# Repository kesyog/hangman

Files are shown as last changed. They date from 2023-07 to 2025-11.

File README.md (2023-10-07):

# hangman ⚖️

<p align="center">
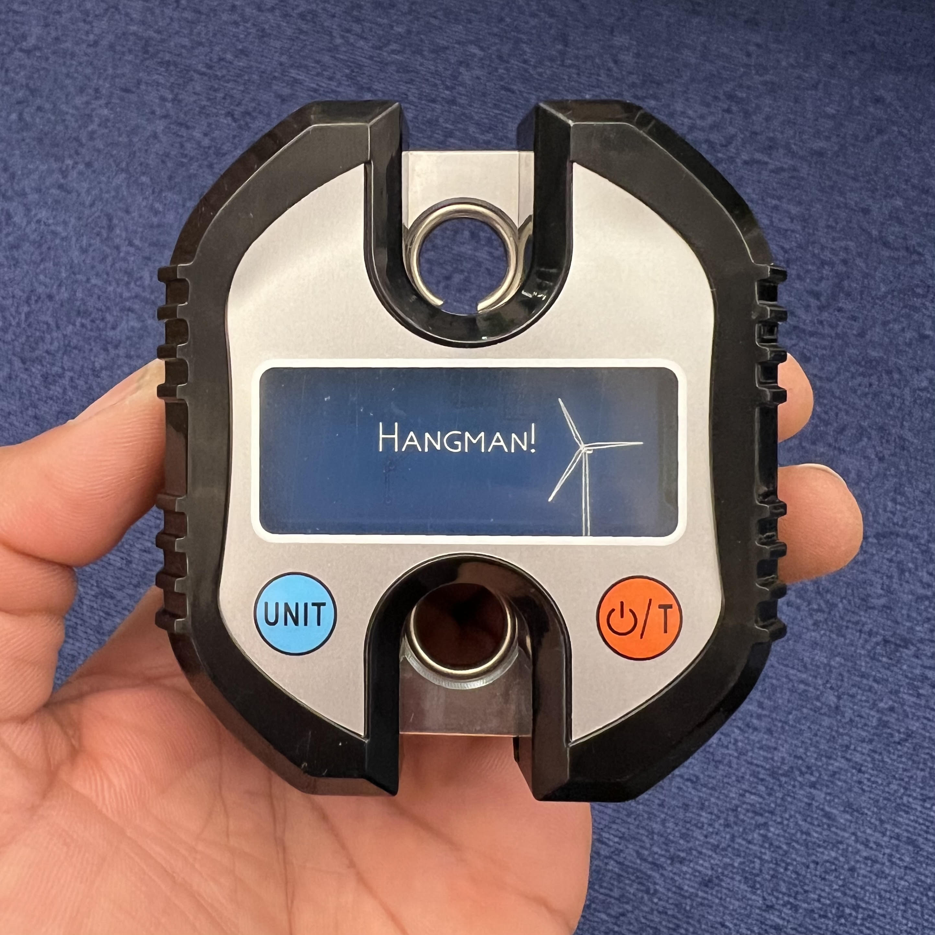
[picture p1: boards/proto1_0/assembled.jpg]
Assembled prototype P1.0 unit
  
</p>

Hangman is a Bluetooth-enabled crane scale. It's intended use is as a climbing training and rehab
tool, but it can be used anywhere that requires measuring force or weight.

The hardware retrofits a cheap (~$23) 150kg crane scale from Amazon with a custom PCB based around a
Nordic nRF52 microcontroller and a differential ADC. The firmware uses [Embassy][Embassy], an
embedded async framework written in Rust, as well as Nordic's SoftDevice Bluetooth stack.

## Why?

Crane scales have become popular in the climbing community as a means to train and rehab fingers.
This is a fun project to learn and practice various concepts I was unfamiliar or rusty with: BLE
101, async Rust on embedded, nRF52 development, SMT soldering and PCB design, etc. Maybe it'll even
help my fingers get stronger.

## Status

The scale is feature-complete. Weight measurement works great with the [Progressor API][API] and
compatible tools. Battery life is guesstimated to be in the range of several months to a couple of
years depending on usage.

There are still a few more software updates planned. See the Issues section for the major ones.

### Hardware revisions

#### P1.0

See title picture. A custom PCB based on a Fanstel BT832 nRF52832-based module and a Texas
Instruments ADS1230 ADC. Thanks to a better ADC and PCB layout, noise performance should be improved
over previous revisions and most importantly, it's much prettier.

#### P0.0

A custom PCB based on a nRF52840 USB dongle and an HX711 ADC, the same differential ADC used on the
Tindeq.

<p align="center">
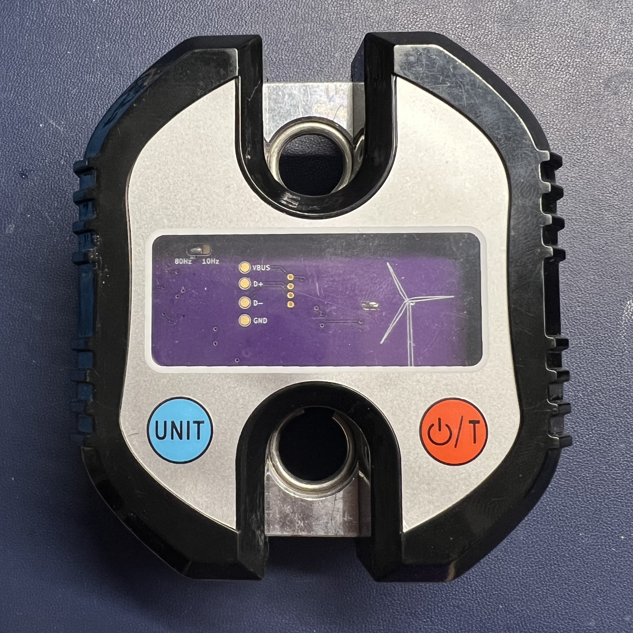
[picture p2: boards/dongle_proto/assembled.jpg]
Assembled prototype P0.0 unit
  
</p>

## Shoutouts

* The [Embassy](https://embassy.dev) project for bringing asynchronous Rust to the embedded world.
  and creating an easy to use wrapper around the Nordic SoftDevice Bluetooth stack.
* [Bumble](https://github.com/google/bumble) for BLE testing and prototyping.
* Texas Instruments for their excellent reference materials on load cell circuit design and PCB
  layout.
* [Tindeq](https://tindeq.com/product/progressor/) for making an amazing product and app and opening
  their BLE API to third-party developers. Go buy one!

## Disclaimer

This is not an officially supported Google product. Wouldn't that be funny though?

This has no affiliation with Tindeq.

[API]: https://tindeq.com/progressor_api/
[Embassy]: https://embassy.dev/

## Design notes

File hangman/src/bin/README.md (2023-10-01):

# Binaries

* `dongle`: prototype based on a nRF52840 USB dongle and an HX711 ADC.
* `calibration`: uses the button for a manual calibration flow. Obsolete now that calibration over
BLE is supported.
* `proto0_0`: custom PCB based on a nRF52840 USB dongle and an HX711 ADC. Fits <https://www.amazon.com/gp/product/B07D5RVW2L>.
* `proto1_0`: custom PCB based on a Fanstel nRF52832 module and a TI ADS1230 ADC. Fits <https://www.amazon.com/gp/product/B07D5RVW2L>.

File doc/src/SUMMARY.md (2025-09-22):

# Summary

[Hangman](./README.md)

- [Development]()
- [Hardware]()
- [Assembly](./assembly.md)
- [Bringup](./bringup.md)
- [Calibration](./calibration.md)

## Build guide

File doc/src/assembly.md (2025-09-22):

# Assembly

How to assemble the boards into the housings

## Instructions
- Test the scale to make sure that it generally works
- Disassemble fully, keep the screws
<p align="center">
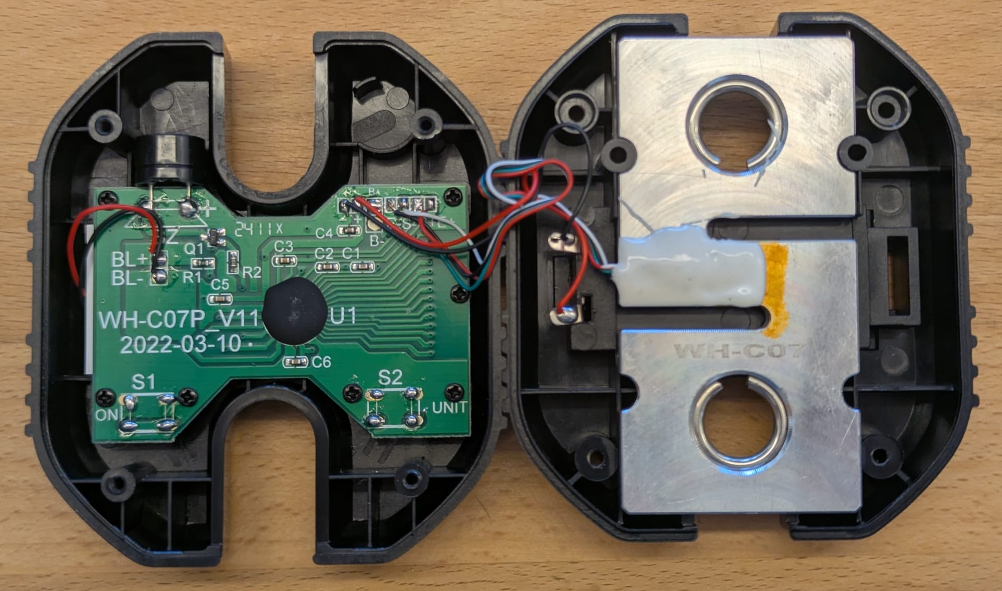
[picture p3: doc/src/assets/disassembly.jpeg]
Partially disassembled scale
  
</p>

- Swap over the wires to the new, already populated PCB
- Screw the new PCB back in 
<p align="center">
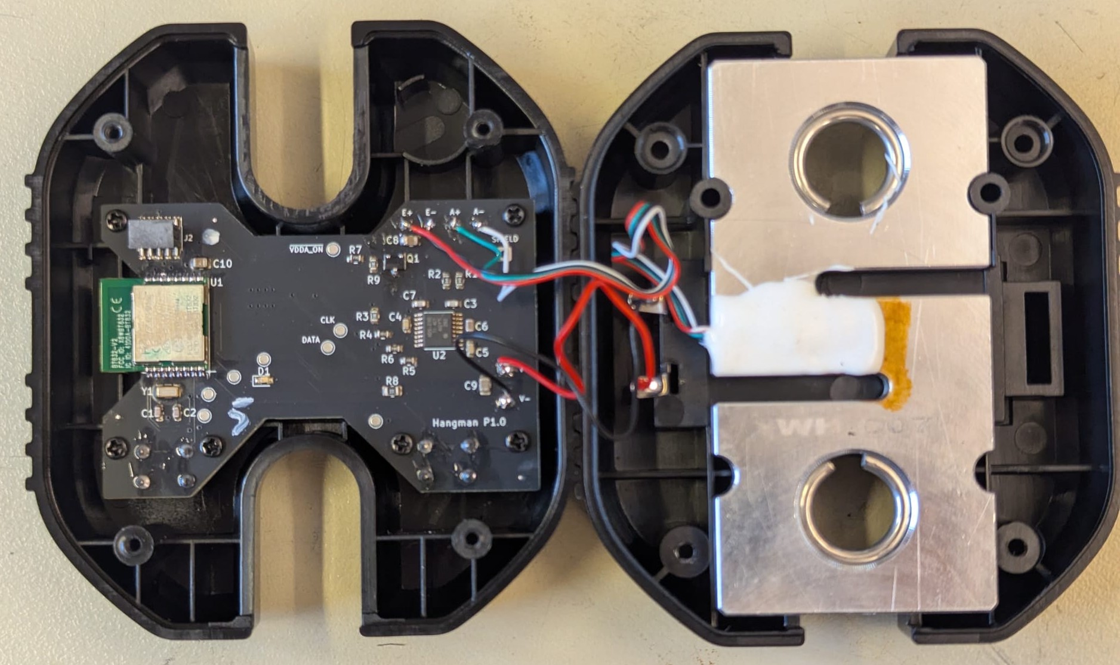
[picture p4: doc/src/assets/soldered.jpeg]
Soldered and semi-assembled scale
  
</p>

- Measure the voltage input pins for shorts (to prevent stupid errors)
- Power on the board with batteries or a lab bench power supply
- Do the [Bringup](./bringup.md)
- Close the housing and screw it shut, don't pinch any wires or strip any screws 
- Do the [Calibration](./calibration.md)
- Done!

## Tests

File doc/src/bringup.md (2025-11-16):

# Bringup

How to get the board from being assembled to being functional

## nRF Command Line Tools + Segger J-Link

Note that Nordic encourages the use of the nRF Util over nrfjprog. I've found nrfjprog to be more
reliable in the past and haven't migrated to nRF Util, but it's probably not too hard to figure out
the equivalent commands.

### Prereqs

* Obtain a Segger J-Link debugger
* Download the [nRF Command Line Tools](https://www.nordicsemi.com/Products/Development-tools/nRF-Command-Line-Tools)
* Download the SoftDevice s113 from <https://www.nordicsemi.com/Products/Development-software/S113>

### Instructions

1. Connect your debugger.
1. Flash the SoftDevice. This generally only needs to be done once.

   ```sh
   nrfjprog --family nrf52 --program s113_nrf52_7.2.0_softdevice.hex --chiperase --verify --reset
   ```

   Your .hex filename may differ.
1. Flash the hangman firmware:

   ```sh
   DEFMT_LOG=info cargo run --release --bin proto1_0 --features nrf52832
   ```

## Windows + ST-Link

Instructions using Windows, WSL and a ST-Link

### Requirements

- Working WSL2
- ST-Link, with installed drivers (I used a ST-Link V2-1, borrowed from a Nucleo Board)
- Install usbipd-win on windows: run `winget install --interactive --exact dorssel.usbipd-win` in a windows terminal
- Install required packages in wsl: `sudo apt install build-essential`
- Install rust: https://rustup.rs/
- Install probe-rs: https://probe.rs/
- Install OpenOCD in WSL: `sudo apt install openocd` in wsl
- Download the SoftDevice for the chip from NRF (I used s113_nrf52_7.3.0_softdevice.hex)

### Flashing

- Connect the ST-Link
- Follow these instructions to get the ST-Link connected to WSL: https://learn.microsoft.com/de-de/windows/wsl/connect-usb
 - `usbipd list`
 - `usbipd bind --busid <busid>`
 - `usbipd attach --wsl --busid <busid>`
- Connect the board to the ST-Link correctly
- Power the board
- Run `openocd -f /usr/share/openocd/scripts/interface/stlink.cfg -f /usr/share/openocd/scripts/target/nrf52.cfg`
- In a seperate terminal run `telnet localhost 4444`
- Use `targets` you can check that you can see the nrf52 target
- Run `init`, `halt`, `nrf5 mass_erase`, `program /full/path/.../s113_nrf52_7.3.0_softdevice.hex verify`
- Run `exit`in telnet shell
- Exit OpenOCD with CTRL+C
- Build and flash the code with `cargo run --bin proto1_0 --release`
- Done! Further flashing etc. should not require reflashing the SoftDevice

### Notes

- If you just want to flash the softdevice in one command you can do it like this: `openocd -f /usr/share/openocd/scripts/interface/stlink.cfg -f /usr/share/openocd/scripts/target/nrf52.cfg -c "init; halt; nrf5 mass_erase; program /full/path/.../s113_nrf52_7.3.0_softdevice.hex preverify verify; shutdown"`

### Sources

- https://www.jentsch.io/nrf51822-flashen-mit-st-link-v2-und-openocd/
- https://github.com/seemoo-lab/openhaystack/wiki/Flashing-nRF-with-OpenOCD---ST-Link
- https://github.com/lupyuen/stm32bluepill-mynewt-sensor/blob/nrf52/scripts/nrf52/flash-boot.sh
- https://www.youtube.com/watch?v=R5wub5ywzTU&t=197s
- https://www.reddit.com/r/embedded/comments/1k9v4vr/stm32_cmake_stlinkv3pwr_on_windows_in_2025/?show=original
- https://github.com/dorssel/usbipd-win/wiki/WSL-support
- https://discuss.ardupilot.org/t/help-setting-up-openocd-with-st-link-in-wsl2/112271
- https://hackmd.io/@aeefs2Y8TMms-cjTDX4cfw/r1fqAa_Da
- https://learn.microsoft.com/de-de/windows/wsl/connect-usb

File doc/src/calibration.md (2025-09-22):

# Calibration

Hangman uses a two-point calibration routine where one of the points is zero. Calibration needs to
be run once before use. The generated calibration constants are saved across power cycles so there
shouldn't be a need to be calibrate multiple times, but you can re-calibrate at any time if you feel
like the scale is inaccurate.

## Instructions

1. Install the nRF Connect app or any similar tool that can be used to connect to BLE devices and
write data to GATT characteristics.
1. Wake up Hangman by pressing the power button.
1. Connect to Hangman using nRF Connect. It'll be named something starting with `Progressor`.
1. Hang "zero" weight from the scale. It's okay if this isn't actually zero. What's important is
that you know the difference in weight between this stage and the second calibration point. Any
deviation from zero at this point will be tared out later.
1. Write the ByteArray `6900000000` to the `7e4e1703-1ea6-40c9-9dcc-13d34ffead57` GATT
characteristic. This should be the only writable characteristic. This sends the 0x69
(`AddCalibrationPoint`) opcode along with 0.0 as a 32-bit float.
1. Add a known reference weight to the scale, ideally something that's at or more than the expected
maximum weight but less than 150kg, the maximum capacity of the scale.
1. Convert the known weight, in kg, to a 32-bit floating point number in little-endian format. Write
`69 <your hex bytes here>` to the same characteristic as earlier. As an example, if your known
weight were 120.0 kg, you would send `690000f042`.
1. If you mess up entering in either meaurement, feel free to resend the corresponding command.
1. Once you're set, write `0x6A` to the same characteristic to save the calibration.
1. At this point, disconnect from Hangman and test it out using the Tindeq mobile app or something
compatible.

## Tips

* If the measurements are wildly off after calibration, try re-calibrating and using a big-endian
float. Different programs disagree on how these bytes should be entered 🤷
* The two calibration points can be written in any order. However, it's probably a little better to
write the zero point first, in case there is some hysteresis.
* 0x69 is the `AddCalibrationPoint` opcode.
* 0x6A is the `SaveCalibration` opcode.

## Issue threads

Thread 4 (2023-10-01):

Documentation tracking

kesyog, 2023-10-01:
* [ ] Calibration instructions
* [ ] Board errata
* [ ] Do a pass of rustdoc comments

cicatrix87, 2024-02-10:
Are you still working on a documentation? I would like to build some of those devices for a few friends, but how its now im a bit confused what and how to do it.

kesyog, 2024-02-11:
Hey, I wasn't planning on writing step-by-step detailed instructions for building these. The process is a bit involved, especially if you don't have soldering and embedded experience and equipment. Also, I'd rather steer people toward getting a [Tindeq](https://tindeq.com/product/progressor) to support their product.

I am planning on writing a high-level guide to document the project further and steer people around some of the obstacles I ran into. It'll live in the attached page, https://kesyog.github.io/hangman. Unfortunately, it's hard to find the time and energy to do this sort of thing so I probably won't get around to it for a while (likely on the order of months at least).

That said, if you do have the background, curiosity, and time to fill in the gaps, the quick summary:
1. Buy this crane scale: https://www.amazon.com/dp/B07MTFXSJW
1. Order the PCB's and electronic parts. I can dig up a parts list if you're interested.
1. Assemble the PCB, ideally with SMT soldering equipment.
1. Replace the existing PCB in the crane scale with your PCB and solder the load cell and battery wires to the PCB.
1. Flash the s113 NRF SoftDevice image using `nrfjprog --family nrf52 --program <path to hex file> --chiperase --verify`. I used a Segger J-Link for flashing.
1. [Install Rust](https://rustup.rs)
1. Build and flash the image. The repo is set up such that `cargo run` will build the image and use `probe-rs` to flash the image.
1. Perform two-point calibration over BLE: https://kesyog.github.io/hangman/calibration.html
1. Enjoy.

Hope that helps!

cicatrix87, 2024-02-12:
I already have a similiar crane scale that could work, in the end those load cells should work identical or? I will check if the originial PCB in this one has the same dimensions and screw points as yours. A Parts List would be highly recommended so a BOM&CPL that i could order everything together with the PCB. Sure i could buy a Tindeq but its more fun like this,

kesyog, 2024-02-12:
It'll almost certainly work with a different load cell as essentially all load cell circuitry works the same way. Most cheap ones have the same 4-wire connection. Some more expensive ones have an additional two sense wires and/or an extra shield line, especially if they have a long cable, but shield can be tied to ground and IIRC the sense lines can either be ignored or tied to the corresponding +/- output lines.

Some things to look out for if you're using a different load cell:
* I'm guessing the the board size and screw points will be different. If needed, you could re-design the boards using the same schematic files to fit the new part. The layout is pretty spacious so there's lots of leeway to move components around to fit a shape
* Make sure the crane scale housing is plastic, not metal, so that it doesn't block wireless transmission.
* Ideally, put the BLE antenna as far away as possible from the metal load cell. I'm not sure how much this matters for the purposes of the crane scale use case where we're probably only ever transmitting over a few meters, but the datasheets recommend keeping the antenna away from metal.
* Make sure the max battery voltage is okay for the nRF52832 microcontroller
* Don't worry about the load cell weight rating. The firmware doesn't care. Once you calibrate it, things should just work, whether you're using a 50kg load cell or a 1000kg load cell.

Also, you'll need a known weight to do calibration, so it's helpful to have an unmodified crane scale (or any kind of scale) to measure your calibration weight.

Here's the part list I used:

| Part              | Ref des     | Part number/Digikey part number   | Notes                                                                                     |
|-------------------|-------------|-----------------------------------|-------------------------------------------------------------------------------------------|
| SWD connector     |             | 1849-PM20B05VBDN-ND               |                                                                                           |
| Fanstel BT module |             | BT832                             | https://www.fanstel.com/bt832-1-1                                                         |
| Push-button       |             | 2223-TS02-66-70-BK-160-LCR-D-ND   |                                                                                           |
| TI ADC            |             | ADS1230                           | https://www.digikey.com/en/products/detail/texas-instruments/ADS1230IPWR/1689136          |
| PFET              | Q1          | SSM3J378RLFCT-ND                  |                                                                                           |
| 32.768kHz crystal |             | SC32S-7PF20PPM                    | https://www.digikey.com/en/products/detail/seiko-instruments/SC32S-7PF20PPM/4931504       |
| RLED              | R8          | RMCF0805JT100RCT-ND               | (for debugging)                                                                           |
| LED               |             | 3147-B1911USD-20D000114U1930CT-ND | (for debugging)                                                                           |
| 10pF              | C1 C2       | 1276-1069-1-ND                    |                                                                                           |
| 0.1uF filter caps | C6          | 490-GRMJN65C1H104JE01JCT-ND       | https://www.digikey.com/en/products/detail/murata-electronics/GRMJN65C1H104JE01J/19115572 |
| 10nF filter caps  | C3 C7       | 490-GRT1885C1E103JA02JCT-ND       |                                                                                           |
| 0.1uF             | C4 C5       | 1276-1935-1-ND                    |                                                                                           |
| 10uF              | C8 C9 C10   | 1276-2399-1-ND                    |                                                                                           |
|                47 | R4 R5 R6 R7 | RMCF0603FT47R5CT-ND               |                                                                                           |
|               100 | R1 R2       | RMCF0603FT100RCT-ND               |                                                                                           |
| 49.9k             | R3 R9       | RMCF0603FT49K9CT-ND               |                                                                                           |

Let me know if/when you get it working. I won't be able to give too much debugging help, but I might be able to point you to relevant docs I found helpful.

roviraleix, 2024-06-20:
Hello,

any updates on it? I've got an nRF52840 board and a HX711 and would like to try to make it work with the tindeq app.
I was wondering if it would be possible to flash the nRF with the tindeq firmware.

Regards and congrats for this nice project!

RaBoom, 2025-08-10:
Hi,

as I want to order a few boards, I have put together a (slightly updated) digikey BOM:
https://www.digikey.de/de/mylists/list/5ZJBLSF5TQ
I have selected a new LED (other one was not in Stock anymore) and put in a 330 Ohm resistor for the debug LED.

To save some money I have opted to buy the TI ADS1230IPWR and the headers (20021121-00010C4LF) at LCSC.

I will order the PCBs and stencils at JLC and assemble them at home and will try to document my process a bit.
If anyone in europe wants an assembled board shoot me a message, I will probably have some left over to offer for approx. 20€+ Shipping (I hope thats okay for you @kesyog)

Cicatr1x, 2025-08-11:
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

If you have some spares leftover, than i would probably take two units.

RaBoom, 2025-09-03:
> If you have some spares leftover, than i would probably take two units.

Sure! I've finished the first one and it works great!

Contact me at rboomgaarden at gmx dot de
I'll immediately delete this comment and will rely on your notifications so that you are able to see this :)

kesyog, 2025-09-03:
ah sorry about that. IIRC I ran into those issues during assembly and fixed the Kicad files but must have forgotten to re-generate the gerbers. Do you think it'd be better if I just removed the gerbers from git so that the Kicad files are the single source of truth?

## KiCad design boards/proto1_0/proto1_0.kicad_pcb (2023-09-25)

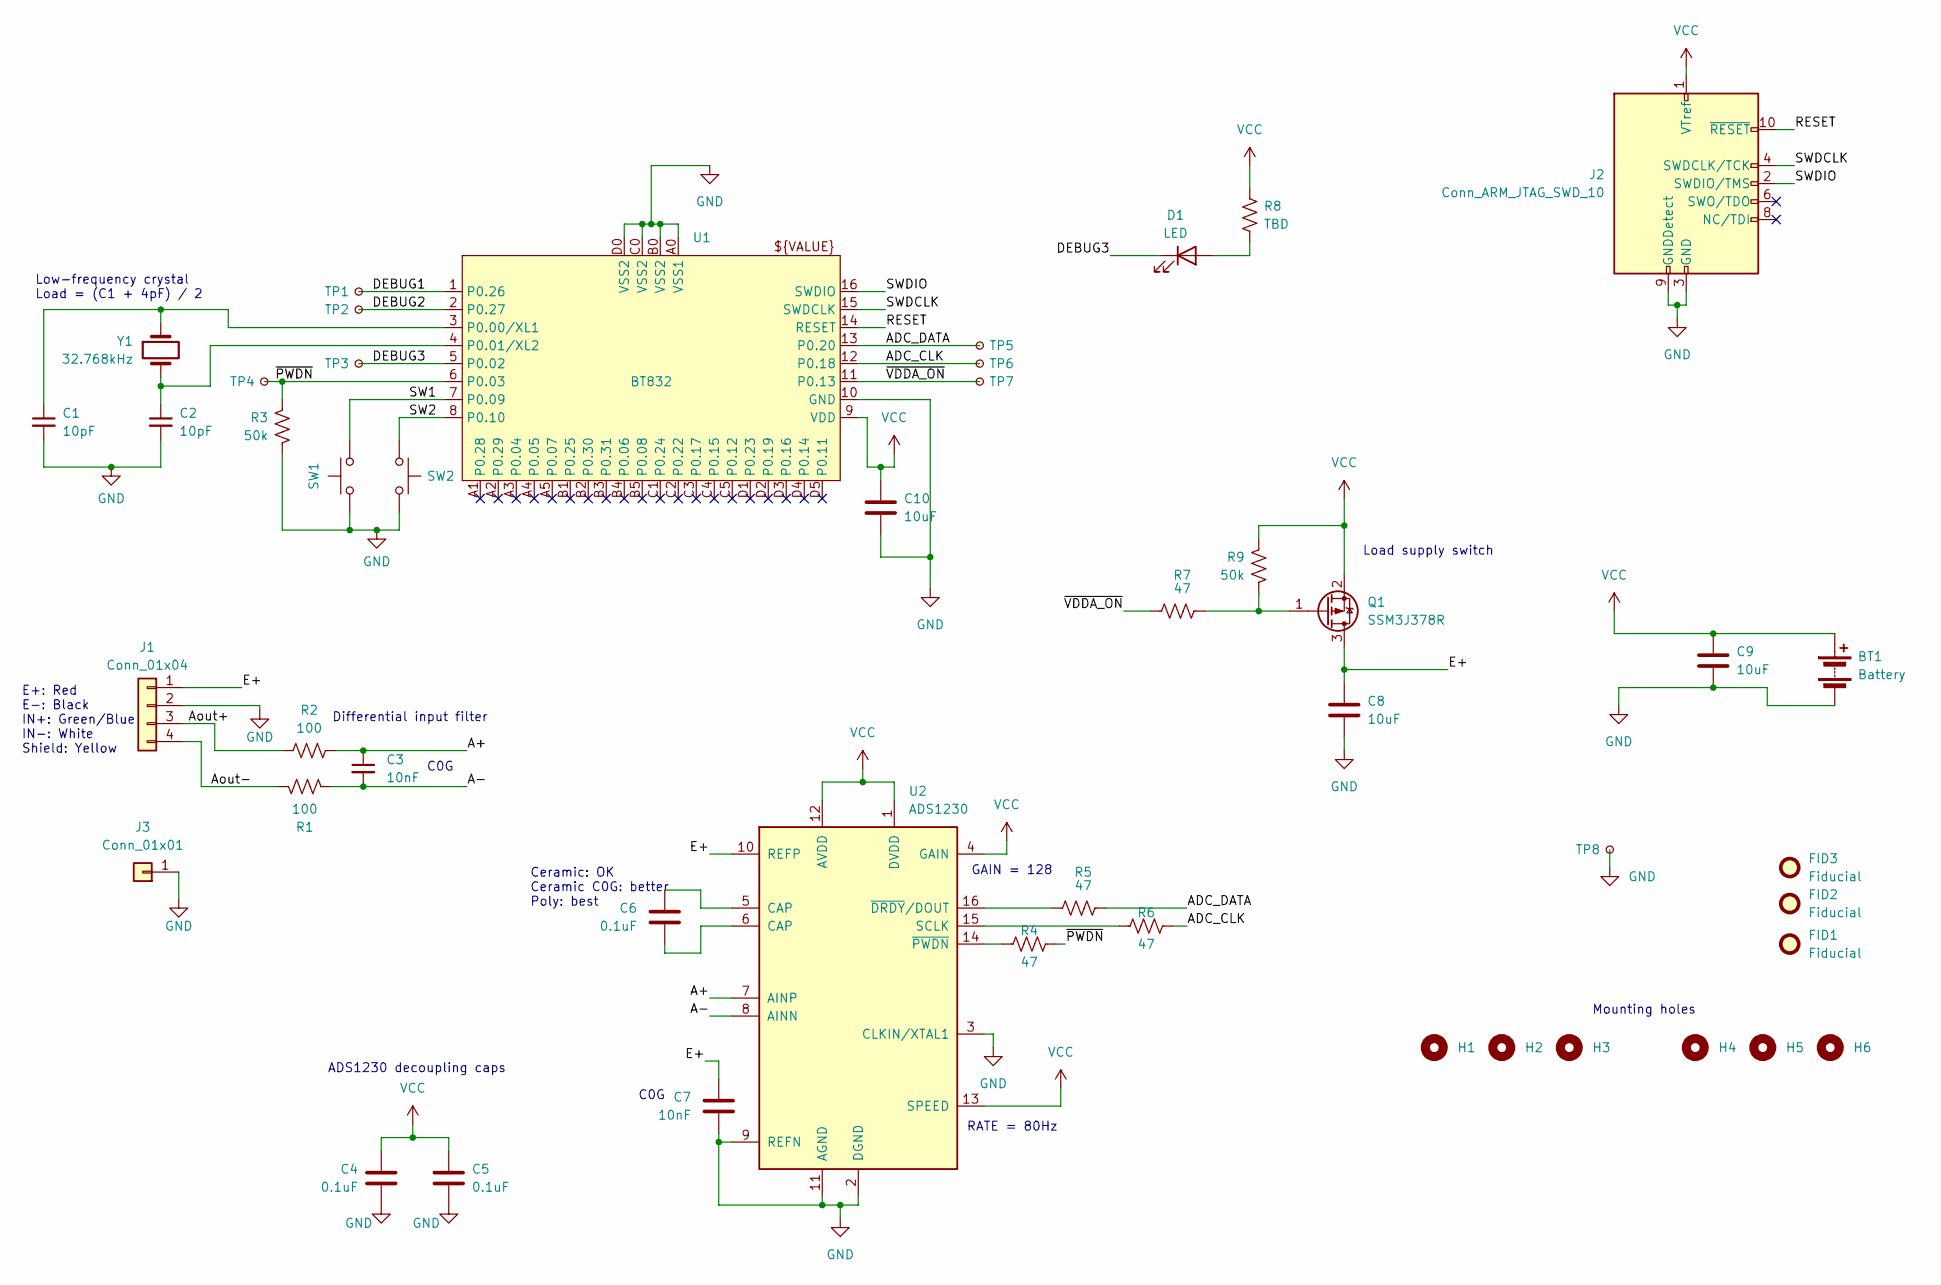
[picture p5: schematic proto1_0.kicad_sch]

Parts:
BT1: Battery; SolderWire-0.5sqmm_1x02_P4.6mm_D0.9mm_OD2.1mm
C1, C2: 10pF; C_0603_1608Metric
C3, C7: 10nF; C_0603_1608Metric
C4, C5, C6: 0.1uF; C_0603_1608Metric
C8, C9, C10: 10uF; C_0805_2012Metric
D1: LED; LED_0603_1608Metric_Pad1.05x0.95mm_HandSolder
FID1, FID2, FID3: Fiducial; Fiducial_0.5mm_Mask1mm
H1, H2, H3, H4, H5, H6: MountingHole; MountingHole_2.2mm_M2
J1: Conn_01x04; SolderWire-0.1sqmm_1x04_P3.6mm_D0.4mm_OD1mm
J2: Conn_ARM_JTAG_SWD_10; PinHeader_2x05_P1.27mm_Vertical_SMD
J3: Conn_01x01; SolderWire-0.5sqmm_1x01_D0.9mm_OD2.1mm
Q1: SSM3J378R; SOT-23
R1, R2: 100; R_0603_1608Metric
R3, R9: 50k; R_0603_1608Metric
R4, R5, R6, R7: 47; R_0603_1608Metric
R8: TBD; R_0805_2012Metric
SW1, SW2: 2223-TS02-66-70-BK-160-LCR-D-ND (Digikey); SW_PUSH_6mm_H7.3mm
TP1, TP2, TP3, TP4, TP5, TP6, TP7, TP8: TestPoint_Small; TestPoint_Pad_D1.5mm
U1: BT832
U2: ADS1230; TSSOP-16_4.4x5mm_P0.65mm
Y1: 32.768kHz; Crystal_SMD_3215-2Pin_3.2x1.5mm; Part number SC32S-7PF20PPM

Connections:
/A+: C3.1, R2.2, U2.7 (AINP)
/A-: C3.2, R1.2, U2.8 (AINN)
/ADC_CLK: R6.2, TP6.1, U1.12 (P0.18)
/ADC_DATA: R5.2, TP5.1, U1.13 (P0.20)
/Aout+: J1.3, R2.1
/Aout-: J1.4, R1.1
/DEBUG1: TP1.1, U1.1 (P0.26)
/DEBUG2: TP2.1, U1.2 (P0.27)
/DEBUG3: D1.1 (K), TP3.1, U1.5 (P0.02)
/E+: C7.1, C8.1, J1.1, Q1.3 (D), U2.10 (REFP)
/RESET: J2.10 (~RESET), U1.14 (RESET)
/SW1: SW1.1, U1.7 (P0.09)
/SW2: SW2.1, U1.8 (P0.10)
/SWDCLK: J2.4 (SWDCLK/TCK), U1.15 (SWDCLK)
/SWDIO: J2.2 (SWDIO/TMS), U1.16 (SWDIO)
/~PWDN: R3.1, R4.2, TP4.1, U1.6 (P0.03)
/~VDDA_ON: R7.1, TP7.1, U1.11 (P0.13)
GND: BT1.2 (-), C1.2, C2.2, C4.2, C5.2, C7.2, C8.2, C9.2, C10.2, J1.2, J2.3 (GND), J2.5 (GND), J2.9 (GNDDetect), J3.1, R3.2, SW1.2, SW2.2, TP8.1, U1.10 (GND), U1.A0 (VSS1), U1.B0 (VSS2), U1.C0 (VSS2), U1.D0 (VSS2), U2.2 (DGND), U2.3 (CLKIN/XTAL1), U2.9 (REFN), U2.11 (AGND)
unnamed: C6.1, U2.5 (CAP)
unnamed: C6.2, U2.6 (CAP)
unnamed: D1.2 (A), R8.2
unnamed: Q1.1 (G), R7.2, R9.2
unnamed: C1.1, U1.3 (P0.00/XL1), Y1.1
unnamed: C2.1, U1.4 (P0.01/XL2), Y1.2
unnamed: R6.1, U2.15 (SCLK)
unnamed: R5.1, U2.16 (~DRDY/DOUT)
unnamed: R4.1, U2.14 (~PWDN)
VCC: BT1.1 (+), C4.1, C5.1, C9.1, C10.1, J2.1 (VTref), Q1.2 (S), R8.1, R9.1, U1.9 (VDD), U2.1 (DVDD), U2.4 (GAIN), U2.12 (AVDD), U2.13 (SPEED)

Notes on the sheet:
Load supply switch
E+: Red E-: Black IN+: Green/Blue IN-: White Shield: Yellow
Differential input filter
Low-frequency crystal Load = (C1 + 4pF) / 2
C0G
Mounting holes
RATE = 80Hz
GAIN = 128
Ceramic: OK Ceramic C0G: better Poly: best
ADS1230 decoupling caps

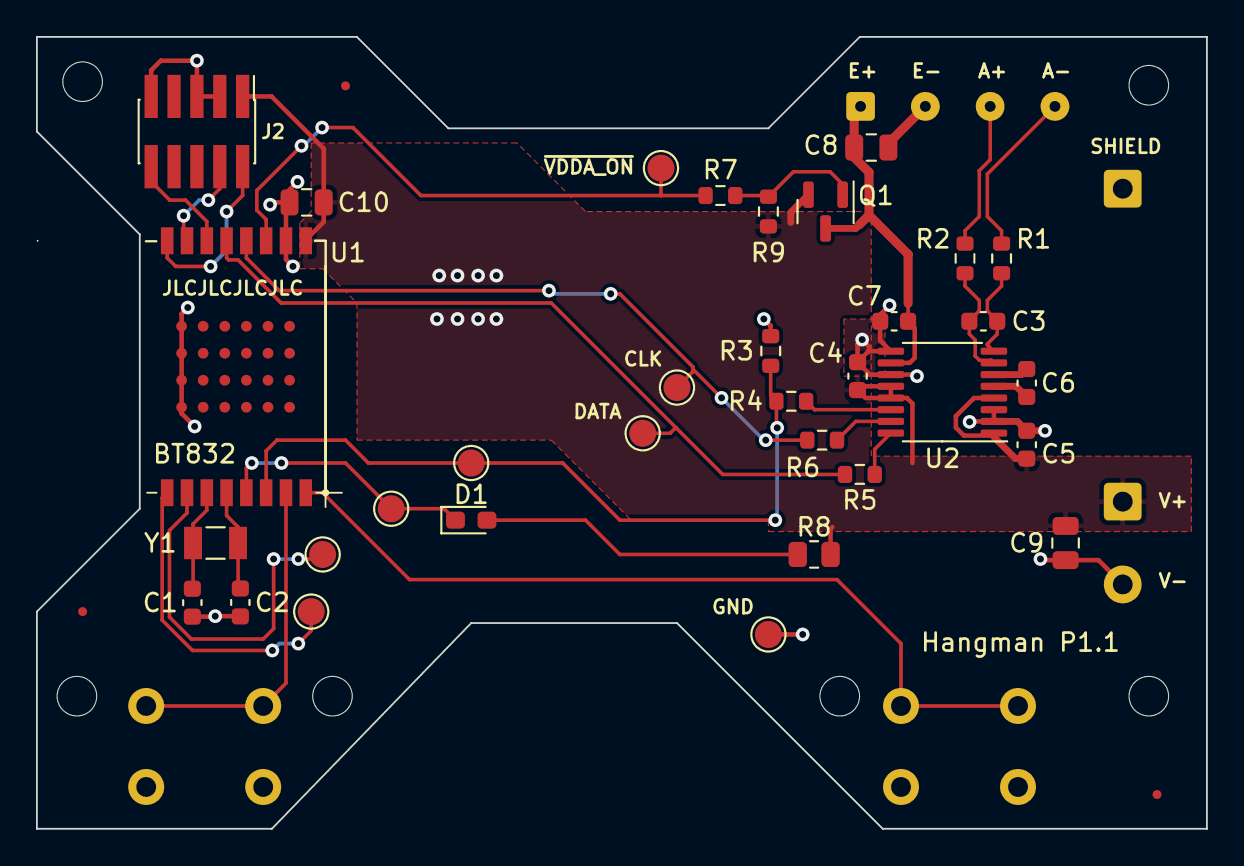
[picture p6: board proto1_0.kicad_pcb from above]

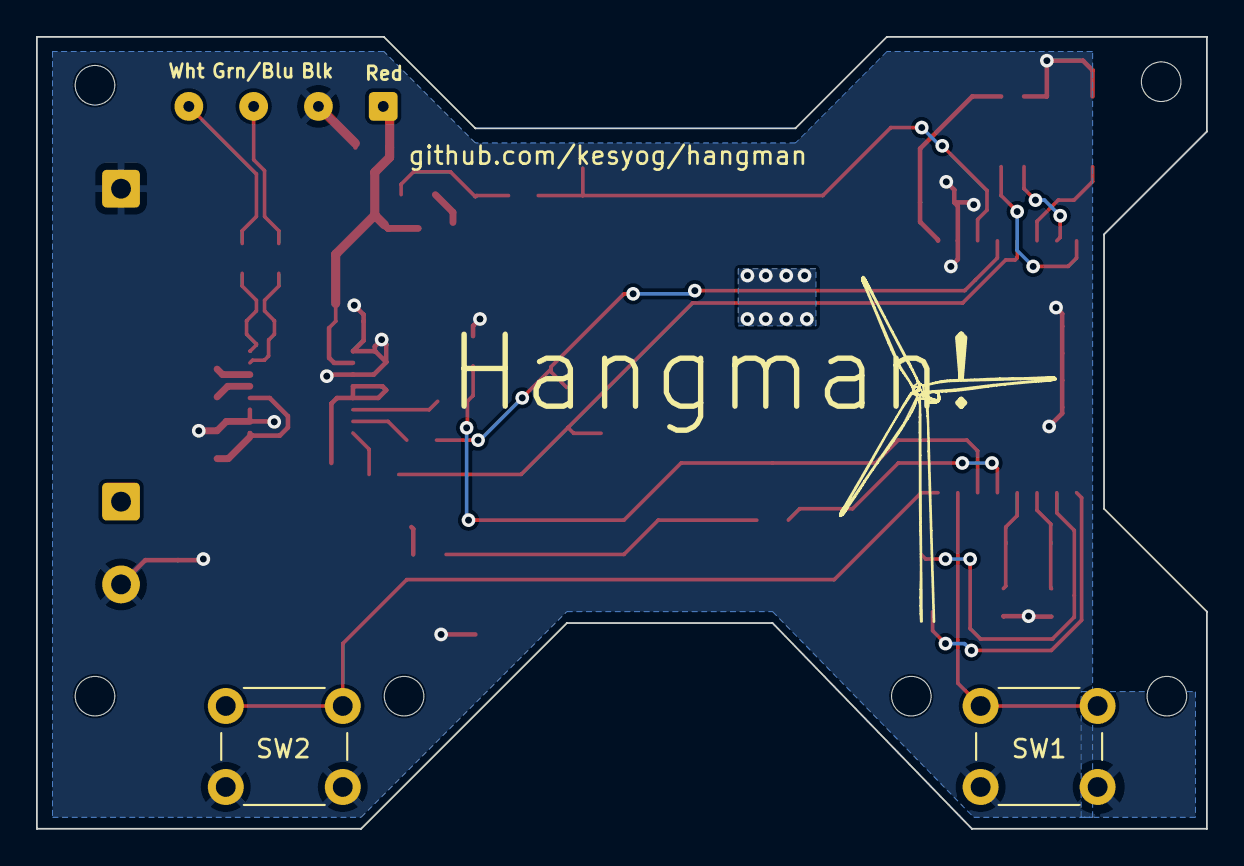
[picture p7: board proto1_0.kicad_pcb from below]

Board: 2 copper layers, 65.0 x 44.0 mm, 47 parts (2 on the bottom side), 28 nets.

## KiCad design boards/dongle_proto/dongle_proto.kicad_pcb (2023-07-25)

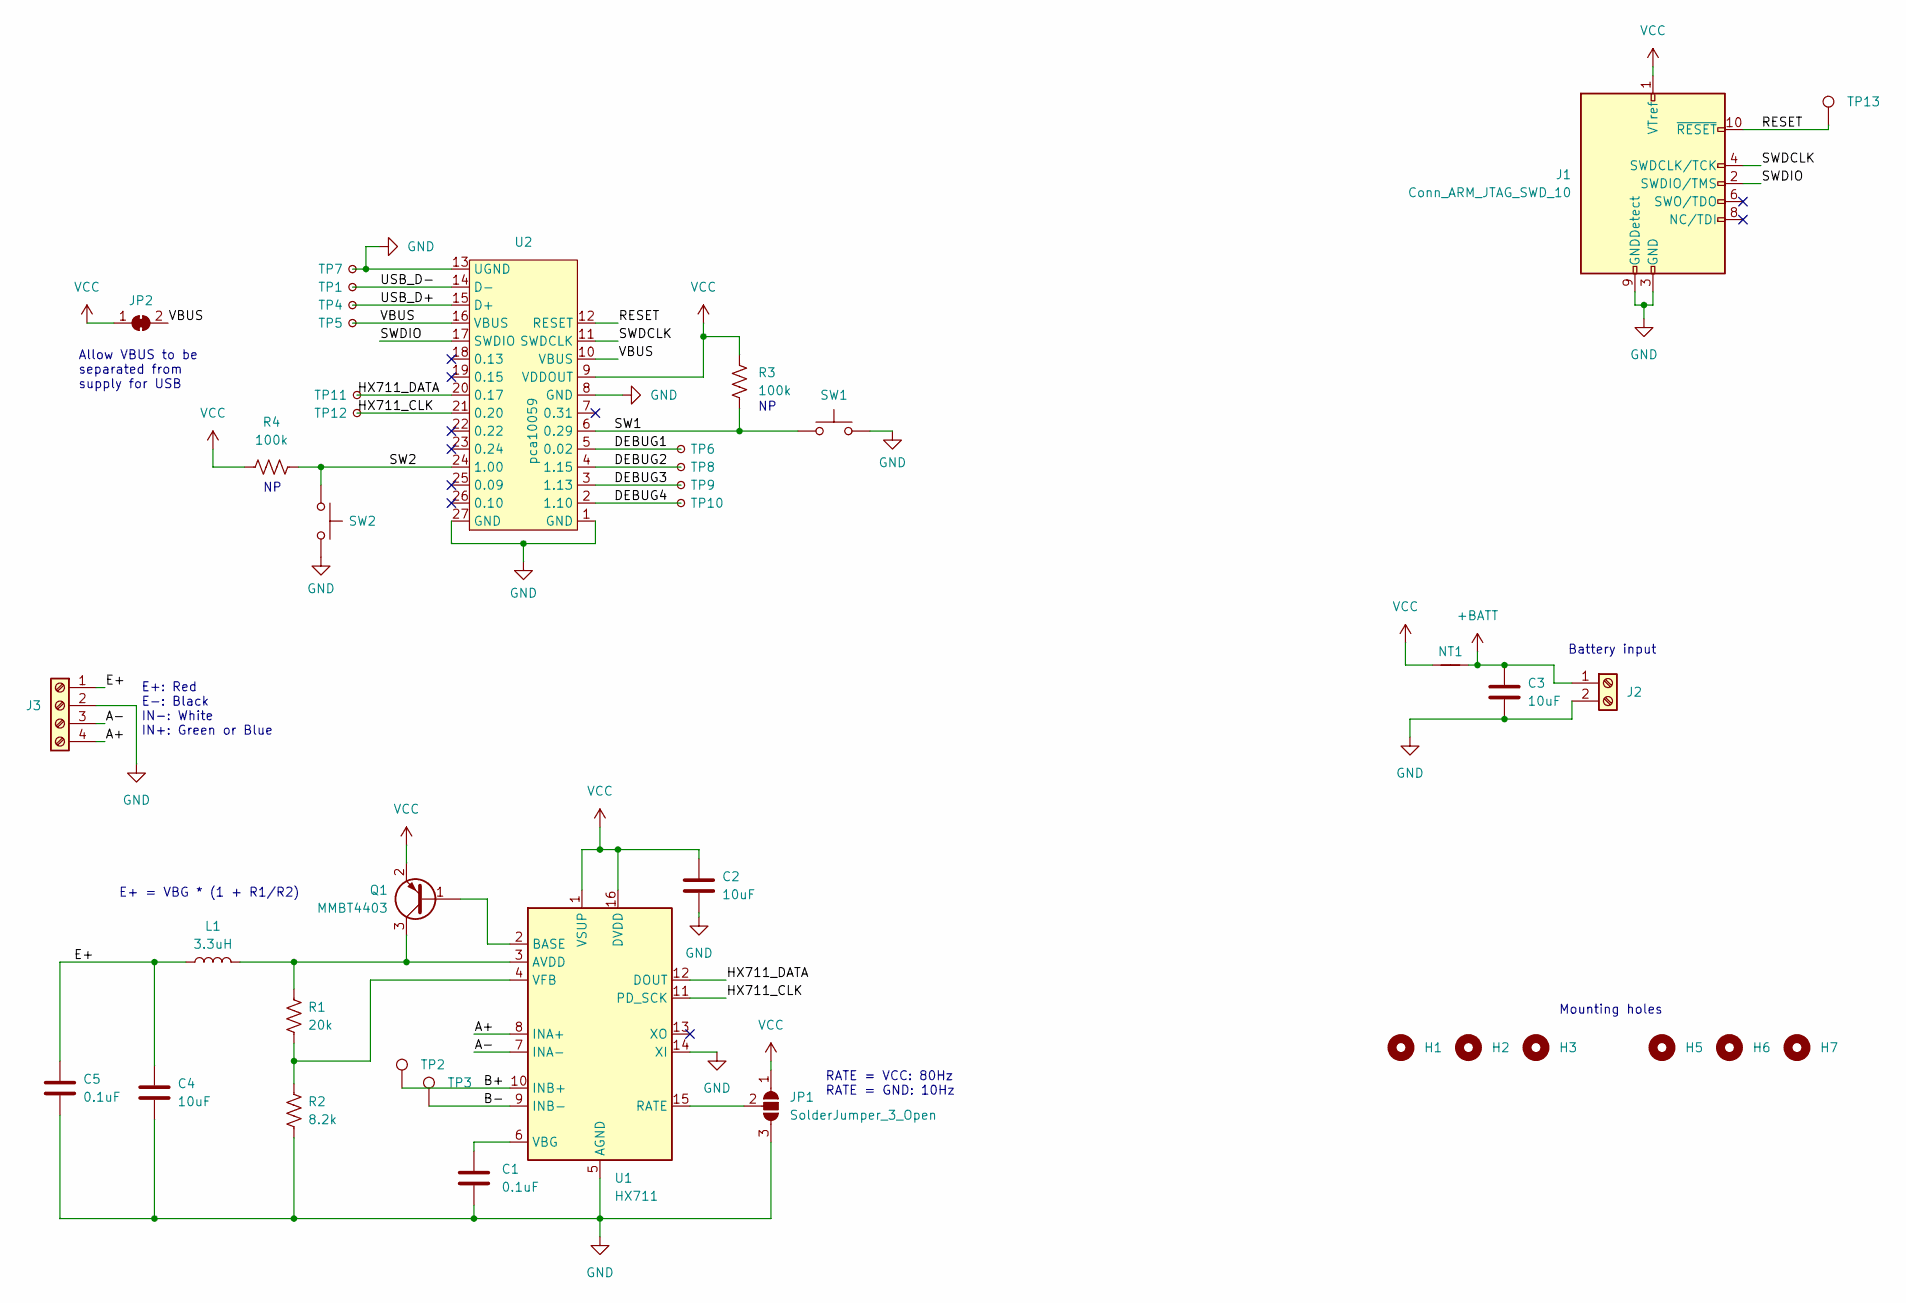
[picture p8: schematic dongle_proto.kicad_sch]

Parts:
C1, C5: 0.1uF; C_0805_2012Metric_Pad1.18x1.45mm_HandSolder
C2, C3, C4: 10uF; C_0805_2012Metric_Pad1.18x1.45mm_HandSolder
H1, H2, H3, H5, H6, H7: MountingHole; MountingHole_2.2mm_M2
J1: Conn_ARM_JTAG_SWD_10; PinHeader_2x05_P1.27mm_Vertical_SMD
J2: Screw_Terminal_01x02; TerminalBlock_Phoenix_MPT-0,5-2-2.54_1x02_P2.54mm_Horizontal
J3: Screw_Terminal_01x04; TerminalBlock_Phoenix_MPT-0,5-4-2.54_1x04_P2.54mm_Horizontal
JP1: SolderJumper_3_Open; SolderJumper-3_P1.3mm_Open_RoundedPad1.0x1.5mm
JP2: SolderJumper_2_Bridged; SolderJumper-2_P1.3mm_Bridged_RoundedPad1.0x1.5mm
L1: 3.3uH; L_0805_2012Metric_Pad1.05x1.20mm_HandSolder
NT1: NetTie_2; NetTie-2_SMD_Pad2.0mm
Q1: MMBT4403; SOT-23_Handsoldering
R1: 20k; R_0805_2012Metric_Pad1.20x1.40mm_HandSolder
R2: 8.2k; R_0805_2012Metric_Pad1.20x1.40mm_HandSolder
R3, R4: 100k; R_0805_2012Metric_Pad1.20x1.40mm_HandSolder
SW1, SW2: 2223-TS02-66-70-BK-160-LCR-D-ND (Digikey); SW_PUSH_6mm_H7.3mm
TP1, TP4, TP5, TP6, TP7, TP8, TP9, TP10, TP11, TP12: TestPoint_Small; TestPoint_Pad_D1.5mm
TP2, TP3, TP13: TestPoint; TestPoint_Pad_D1.5mm
U1: HX711; SOP-16_3.9x9.9mm_P1.27mm
U2: pca10059

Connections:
+BATT: C3.1, J2.1, NT1.2
/A+: J3.4, U1.8 (INA+)
/A-: J3.3, U1.7 (INA-)
/B+: TP2.1, U1.10 (INB+)
/B-: TP3.1, U1.9 (INB-)
/DEBUG1: TP6.1, U2.5 (0.02)
/DEBUG2: TP8.1, U2.4 (1.15)
/DEBUG3: TP9.1, U2.3 (1.13)
/DEBUG4: TP10.1, U2.2 (1.10)
/E+: C4.1, C5.1, J3.1, L1.1
/HX711_CLK: TP12.1, U1.11 (PD_SCK), U2.21 (0.20)
/HX711_DATA: TP11.1, U1.12 (DOUT), U2.20 (0.17)
/RESET: J1.10 (~RESET), TP13.1, U2.12 (RESET)
/SW1: R3.2, SW1.1, U2.6 (0.29)
/SW2: R4.2, SW2.1, U2.24 (1.00)
/SWDCLK: J1.4 (SWDCLK/TCK), U2.11 (SWDCLK)
/SWDIO: J1.2 (SWDIO/TMS), U2.17 (SWDIO)
/USB_D+: TP4.1, U2.15 (D+)
/USB_D-: TP1.1, U2.14 (D-)
/VBUS: JP2.2 (B), TP5.1, U2.10 (VBUS), U2.16 (VBUS)
GND: C1.2, C2.2, C3.2, C4.2, C5.2, J1.3 (GND), J1.5 (GND), J1.9 (GNDDetect), J2.2, J3.2, JP1.3 (B), R2.2, SW1.2, SW2.2, TP7.1, U1.5 (AGND), U1.14 (XI), U2.1 (GND), U2.8 (GND), U2.13 (UGND), U2.27 (GND)
unnamed: JP1.2 (C), U1.15 (RATE)
unnamed: Q1.1 (B), U1.2 (BASE)
unnamed: L1.2, Q1.3 (C), R1.1, U1.3 (AVDD)
unnamed: C1.1, U1.6 (VBG)
unnamed: R1.2, R2.1, U1.4 (VFB)
VCC: C2.1, J1.1 (VTref), JP1.1 (A), JP2.1 (A), NT1.1, Q1.2 (E), R3.1, R4.1, U1.1 (VSUP), U1.16 (DVDD), U2.9 (VDDOUT)

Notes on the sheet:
Battery input
E+: Red E-: Black IN-: White IN+: Green or Blue
Mounting holes
E+ = VBG * (1 + R1/R2)
Allow VBUS to be separated from supply for USB
RATE = VCC: 80Hz RATE = GND: 10Hz

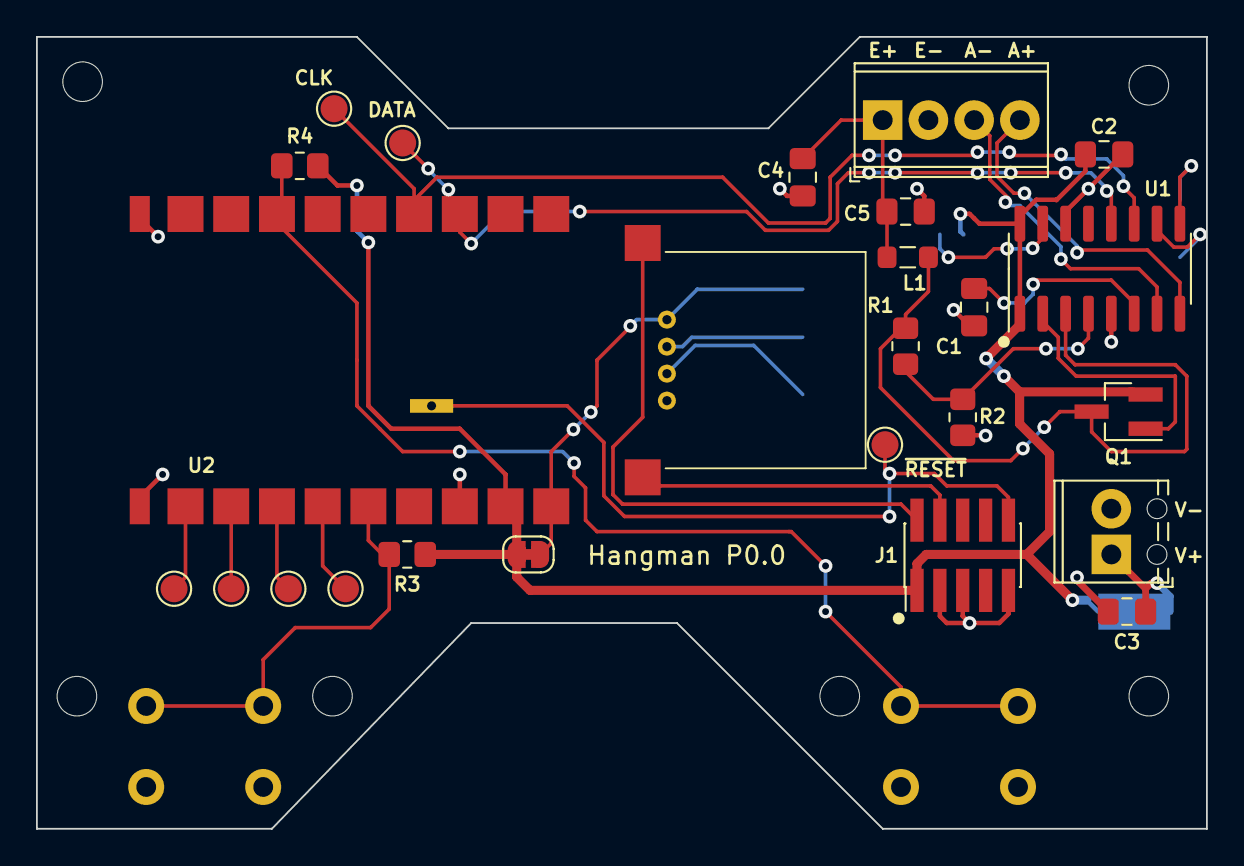
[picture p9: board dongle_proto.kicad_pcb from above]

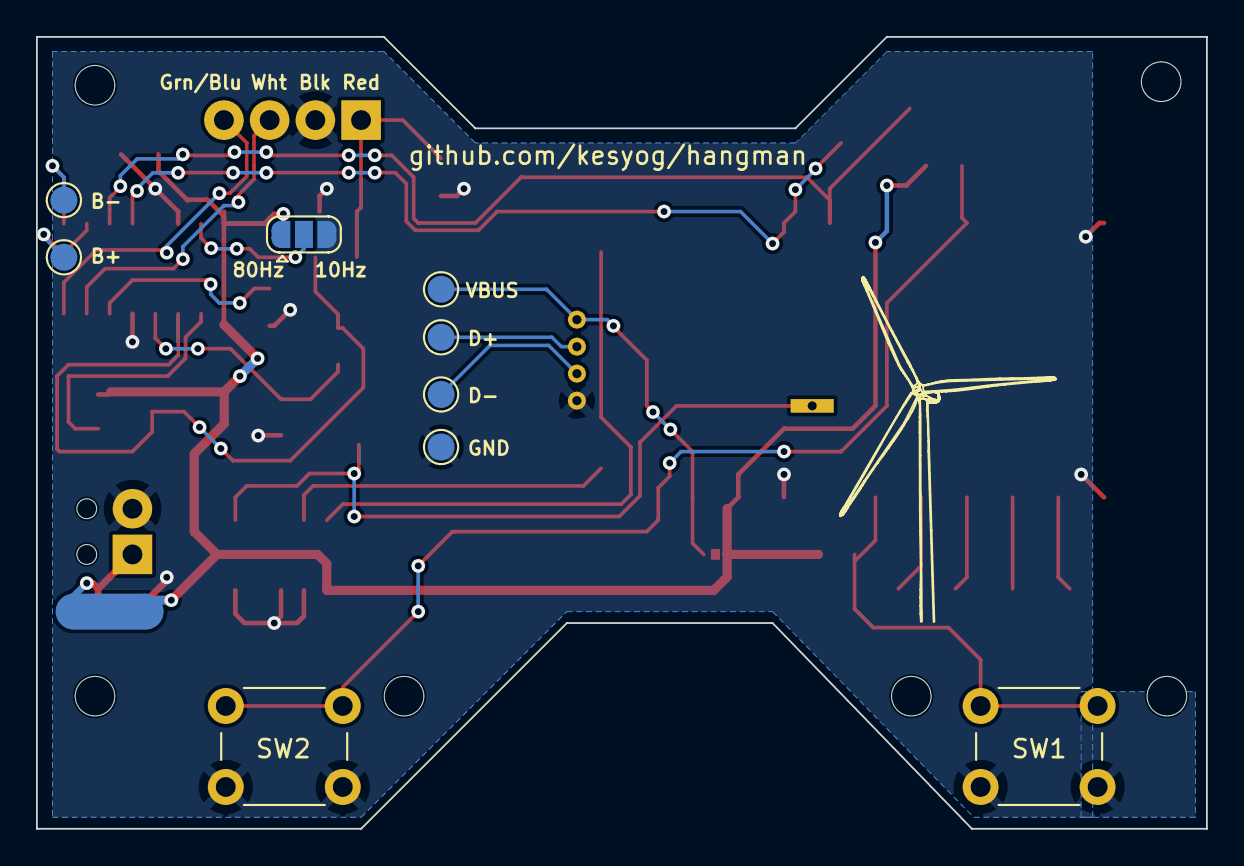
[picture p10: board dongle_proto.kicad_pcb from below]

Board: 2 copper layers, 65.0 x 44.0 mm, 40 parts (10 on the bottom side), 27 nets.

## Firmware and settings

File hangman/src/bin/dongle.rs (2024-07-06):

// Copyright 2023 Google LLC
//
// Licensed under the Apache License, Version 2.0 (the "License");
// you may not use this file except in compliance with the License.
// You may obtain a copy of the License at
//
//     https://www.apache.org/licenses/LICENSE-2.0
//
// Unless required by applicable law or agreed to in writing, software
// distributed under the License is distributed on an "AS IS" BASIS,
// WITHOUT WARRANTIES OR CONDITIONS OF ANY KIND, either express or implied.
// See the License for the specific language governing permissions and
// limitations under the License.

#![no_main]
#![cfg_attr(not(test), no_std)]
#![feature(type_alias_impl_trait)]
#![forbid(unsafe_op_in_unsafe_fn)]

#[cfg(not(feature = "nrf52840"))]
compile_error!("Dongle proto uses nRF52840");

extern crate alloc;

use blocking_hal::Delay as SysTickDelay;
use defmt_rtt as _;
use embassy_executor::Spawner;
use embassy_nrf::{
    config::{Config, HfclkSource, LfclkSource},
    gpio::{self, Pin},
    usb::vbus_detect::SoftwareVbusDetect,
};
use embassy_sync::{channel::Channel, mutex::Mutex};
use embassy_time::{Duration, Timer};
use embedded_alloc::Heap;
#[cfg(feature = "console")]
use hangman::console;
use hangman::{
    battery_voltage, ble, blocking_hal,
    button::{self, Button},
    make_static, pac, util,
    weight::{self, Hx711},
    MeasureCommandChannel, SharedDelay,
};
use nrf_softdevice::{self as _, SocEvent, Softdevice};
use panic_probe as _;

#[global_allocator]
/// Create a small heap. Not sure how to pass around closures without one.
static HEAP: Heap = Heap::empty();
// TODO: how to enforce this in the linker script?
const HEAP_SIZE: usize = 1024;

#[cfg(feature = "console")]
embassy_nrf::bind_interrupts!(struct Irqs {
    USBD => embassy_nrf::usb::InterruptHandler<embassy_nrf::peripherals::USBD>;
    SAADC => embassy_nrf::saadc::InterruptHandler;
});

#[cfg(not(feature = "console"))]
embassy_nrf::bind_interrupts!(struct Irqs {
    SAADC => embassy_nrf::saadc::InterruptHandler;
});

#[embassy_executor::task]
async fn softdevice_task(sd: &'static Softdevice, usb_detect: &'static SoftwareVbusDetect) -> ! {
    defmt::debug!("Starting softdevice task");
    sd.run_with_callback(|event| {
        defmt::debug!("SD event: {}", event);
        match event {
            SocEvent::PowerUsbPowerReady => usb_detect.ready(),
            SocEvent::PowerUsbDetected => usb_detect.detected(true),
            SocEvent::PowerUsbRemoved => usb_detect.detected(false),
            _ => (),
        };
    })
    .await
}

fn config() -> Config {
    // Interrupt priority levels 0, 1, and 4 are reserved for the SoftDevice
    let mut config = Config::default();
    config.hfclk_source = HfclkSource::ExternalXtal;
    config.lfclk_source = LfclkSource::ExternalXtal;
    config.gpiote_interrupt_priority = embassy_nrf::interrupt::Priority::P5;
    config.time_interrupt_priority = embassy_nrf::interrupt::Priority::P5;
    config
}

#[embassy_executor::main]
async fn main(spawner: Spawner) -> ! {
    defmt::println!("Start {=str}!", core::env!("CARGO_BIN_NAME"));
    unsafe {
        HEAP.init(cortex_m_rt::heap_start() as usize, HEAP_SIZE);
        let reset_reason: u32 = (*pac::POWER::ptr()).resetreas.read().bits();
        defmt::info!("Reset reason: {=u32:X}", reset_reason);
        // Reset certain GPIO settings that are retained through system OFF and interfere with the
        // HAL
        util::disable_all_gpio_sense();
    }
    weight::init(weight::Config {
        sampling_interval_hz: 10,
    });

    // This will reset the GPIO latch signal
    let p = embassy_nrf::init(config());
    let syst = pac::CorePeripherals::take().unwrap().SYST;
    let delay: &'static SharedDelay =
        make_static!(SharedDelay, Mutex::new(SysTickDelay::new(syst)));

    // For debugging
    let _green_led = gpio::Output::new(
        p.P0_06.degrade(),
        gpio::Level::High,
        gpio::OutputDrive::Standard,
    );

    // orange DATA 0.17
    let hx711_data = gpio::Input::new(p.P0_17.degrade(), gpio::Pull::None);
    // yellow CLK 0.20
    let hx711_clock = gpio::Output::new(
        p.P0_20.degrade(),
        // Set high initially to power down chip
        gpio::Level::High,
        gpio::OutputDrive::Standard,
    );
    let hx711 = Hx711::new(hx711_data, hx711_clock, delay);

    // USB setup
    // Hack: pretend USB is already connected. not a bad assumption since this is a dongle
    // There might be a race condition at startup between USB init and SD init.
    let usb_detect_ref: &SoftwareVbusDetect =
        make_static!(SoftwareVbusDetect, SoftwareVbusDetect::new(true, true));

    let sd = ble::init_softdevice();
    spawner.must_spawn(softdevice_task(sd, usb_detect_ref));

    // It's recommended to start the SoftDevice before doing anything else
    embassy_futures::yield_now().await;

    // Enable DC-DC converter for power savings. This is okay since the softdevice has been enabled
    // and the dongle has the necessary inductors
    unsafe {
        nrf_softdevice::raw::sd_power_dcdc_mode_set(
            nrf_softdevice::raw::NRF_POWER_DCDC_MODES_NRF_POWER_DCDC_ENABLE as u8,
        )
    };

    #[cfg(feature = "console")]
    let (usb, class) = console::board::setup_usb(p.USBD, Irqs, usb_detect_ref);

    let ch: &MeasureCommandChannel = make_static!(MeasureCommandChannel, Channel::new());
    spawner.must_spawn(weight::task_function(ch.receiver(), hx711, sd));
    // Sample battery voltage while sampling to get a reading under load
    ch.sender()
        .send(weight::Command::StartSampling(weight::SampleType::Raw(
            None,
        )))
        .await;
    let battery_voltage = battery_voltage::one_time_sample(p.SAADC, Irqs).await;
    defmt::info!("Battery voltage: {=u32} mV", battery_voltage);
    ch.sender().send(weight::Command::StopSampling).await;

    #[cfg(feature = "console")]
    {
        spawner.must_spawn(console::task::usb_task(usb));
        spawner.must_spawn(console::task::echo_task(class));
    }

    ch.sender().send(weight::Command::Tare).await;
    // Allow time for tare to complete before starting advertising
    // TODO: make this deterministic
    Timer::after(Duration::from_millis(1000)).await;

    // Use user button for wakeup
    let wakeup_button = Button::new(p.P1_06.degrade(), button::Polarity::ActiveLow, true);
    spawner.must_spawn(ble::task_fn(sd, ch.sender(), wakeup_button));

    loop {
        core::future::pending::<()>().await;
    }
}

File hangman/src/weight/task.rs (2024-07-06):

// Copyright 2023 Google LLC
//
// Licensed under the Apache License, Version 2.0 (the "License");
// you may not use this file except in compliance with the License.
// You may obtain a copy of the License at
//
//     https://www.apache.org/licenses/LICENSE-2.0
//
// Unless required by applicable law or agreed to in writing, software
// distributed under the License is distributed on an "AS IS" BASIS,
// WITHOUT WARRANTIES OR CONDITIONS OF ANY KIND, either express or implied.
// See the License for the specific language governing permissions and
// limitations under the License.

use super::calibrate::Calibrator;
use super::tare::Tarer;
#[cfg(feature = "nrf52832")]
use super::Ads1230;
#[cfg(feature = "nrf52840")]
use super::Hx711;
use super::{average, median::Median, Command, RawReading, Sample, SampleProducerMut, SampleType};
use crate::{make_static, nonvolatile::Nvm, MeasureCommandReceiver};
use embassy_sync::blocking_mutex::raw::NoopRawMutex;
use embassy_sync::mutex::Mutex;
use embassy_time::{Duration, Instant, Timer};
use hangman_utils::two_point_cal::{self, CalPoint, TwoPoint};
use nrf_softdevice::Softdevice;

const THREAD_SLEEP_DELAY: Duration = Duration::from_millis(100);

#[cfg(feature = "nrf52832")]
type Adc = Ads1230<'static>;
#[cfg(feature = "nrf52840")]
type Adc = Hx711<'static>;

type SharedAdc = Mutex<NoopRawMutex, Adc>;
type SharedFilteredAdc = Mutex<NoopRawMutex, Median<&'static SharedAdc>>;
type SharedCalibrator = Mutex<NoopRawMutex, Calibrator<&'static SharedFilteredAdc>>;

enum MeasurementState {
    Idle,
    Active(SampleType, Instant),
}

struct MeasurementContext {
    state: MeasurementState,
    adc: &'static SharedAdc,
    median: &'static SharedFilteredAdc,
    calibrator: &'static SharedCalibrator,
    tarer: Tarer<&'static SharedCalibrator>,
    nvm: Nvm,
    factory_cal: TwoPoint<RawReading>,
}

async fn handle_command(cmd: Command, context: &mut MeasurementContext, adc: &SharedAdc) {
    match cmd {
        Command::StartSampling(measurement_cb) => {
            if !matches!(context.state, MeasurementState::Idle) {
                defmt::error!("Can't start sampling while already measuring");
                return;
            }
            adc.lock().await.power_up().await;
            context.state = MeasurementState::Active(measurement_cb, Instant::now());
        }
        Command::StopSampling => {
            adc.lock().await.power_down();
            context.state = MeasurementState::Idle;
        }
        Command::Tare => {
            if !matches!(context.state, MeasurementState::Idle) {
                defmt::error!("Can't tare while measuring");
                return;
            }

            // 0.5 second
            let warmup = super::sampling_interval_hz() / 2;
            // 0.5 second
            let filter_size = super::sampling_interval_hz() / 2;
            for _ in 0..warmup {
                let _ = context.calibrator.sample().await;
            }
            let mut filter = average::Window::<f32>::new(filter_size);
            for _ in 0..(filter_size - 1) {
                let Sample { value, .. } = context.calibrator.sample().await;
                assert!(filter.add_sample(value).is_none());
            }
            let Sample { value, .. } = context.calibrator.sample().await;
            let average = filter.add_sample(value).unwrap();
            context.tarer.set_offset(average);

            adc.lock().await.power_down();
            context.state = MeasurementState::Idle;
        }
        Command::AddCalibrationPoint(weight) => {
            if !matches!(context.state, MeasurementState::Idle) {
                defmt::error!("Can't run factory cal while measuring");
                return;
            }

            // 1 second
            let warmup = super::sampling_interval_hz();
            // 1 second
            let filter_size = super::sampling_interval_hz();
            for _ in 0..warmup {
                let _ = context.calibrator.sample().await;
            }
            let mut filter = average::Window::<RawReading>::new(filter_size);
            for _ in 0..(filter_size - 1) {
                let Sample { value, .. } = context.median.sample().await;
                assert!(filter.add_sample(value).is_none());
            }
            let Sample { value, .. } = context.median.sample().await;
            let reading = filter.add_sample(value).unwrap();
            context.factory_cal.add_point(CalPoint {
                expected_value: weight,
                measured_value: reading,
            });
        }
        Command::SaveCalibration => {
            if let Some(two_point_cal::Constants { m, b }) = context.factory_cal.get_cal_constants()
            {
                defmt::info!("New calibration: m = {=f32} b = {=i32}", m, b);
                super::write_calibration(&mut context.nvm, m, b).await;
                context.calibrator.lock().await.set_calibration(m, b);
            } else {
                defmt::error!("Not enough data points to calibrate");
            }
        }
    }
}

async fn measure(context: &mut MeasurementContext) {
    let MeasurementState::Active(ref mut sample_type, ref mut start_time) = context.state else {
        return;
    };
    let mut calculate_duration =
        |timestamp: Instant| match timestamp.checked_duration_since(*start_time) {
            Some(duration) => duration,
            None => {
                *start_time = timestamp;
                Duration::from_ticks(0)
            }
        };
    match sample_type {
        SampleType::Raw(cb) => {
            let Sample { timestamp, value } = context.adc.sample().await;
            if let Some(cb) = cb {
                cb(calculate_duration(timestamp), value);
            }
        }
        SampleType::FilteredRaw(cb) => {
            let Sample { timestamp, value } = context.median.sample().await;
            if let Some(cb) = cb {
                cb(calculate_duration(timestamp), value);
            }
        }
        SampleType::Calibrated(cb) => {
            let Sample { timestamp, value } = context.calibrator.sample().await;
            if let Some(cb) = cb {
                cb(calculate_duration(timestamp), value);
            }
        }
        SampleType::Tared(cb) => {
            let Sample { timestamp, value } = context.tarer.sample().await;
            if let Some(cb) = cb {
                cb(calculate_duration(timestamp), value);
            }
        }
    };
}
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

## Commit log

2023-02-05 Switch to Embassy executor and HAL
    Using the async Embassy framework will be required to use the
    `nrf-softdevice` crate, which we'll likely later use to access the
    SoftDevice.
2023-02-11 Add logging over RTT
    * Add support for defmt logging over RTT
    * Switch cargo runner to probe-run, which supports defmt parsing
2023-02-26 Hook up HX711 driver to GATT commands
    * Add bit-banged HX711 driver
    * Add some default calibration constants
    * Show status with LED's
    * Reduce RAM section size to simulate smallest nRF52 chip
    It works with the Tindeq app!
2023-02-26 Add NVM driver to store calibration constants
    Bonus: lower most `println` logs to lower priorities
2023-07-16 Make reported sample timestamps more accurate
    Treat the moment that the HX711 reports a sample is ready as the sample
    time. We were previously reading a timestamp after the sample had been
    shifted out to the processor, which introduces a relatively fixed offset
    that shouldn't matter in practice, but accuracy is accuracy.
2023-07-25 🤞🏽 Add Kicad files for P0.0 prototype board
    Add schematic, symbol library, footprint library, and layout for P0.0
    prototype board.
    [dongle_proto.kicad_pcb, dongle_proto.kicad_sch]
2023-07-29 🧹 Refactor weight sampling code
    Goals:
    * Make it easier to add new functionality, especially filtering (for
    calibration and taring) and a calibration flow.
    * Clean up a lot of cruft that made things extra hard to follow and
    edit.
    Changes:
    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
2023-07-29 Fix crash in Flash driver
    Flash transactions must only be performed with 4-byte aligned buffers
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2023-08-17 Fix HX711 AVDD level
    The HX711's analog output (AVDD) should be set below its supply voltage
    (the battery voltage) so that the chip's feedback loop can create a
    stable excitation voltage that is resilient to load transients. The
    R1/R2 resistor ladder was set such that AVDD would always rail to the
    supply voltage. Set it to ~2.7-2.8V instead.
    Note: it's possible that this doesn't actually matter since the ADC
    makes ratiometric measurements (the reference is the same as the supply
    voltage) and may actually hurt SNR.
    [dongle_proto.kicad_sch]
2023-08-17 Reduce sample noise + miscellaneous cleanup
    * Add 5-point median filter in sample pipeline to filter glitches in
    samples
    * Use `make_static!` convenience macro to initialize `StaticCell`s
    * Disable LED's to save power
    * Store window size in window average rather than using const generics
    to reduce monomorphization code bloat.
    * Add some warmup time on HX711 startup to account for settling time and
    allow for some temperature stabilization.
    [task.rs]
2023-08-21 Create separate binary for manual calibration
    Stuffing everything into one binary was becoming increasingly painful.
    Create a lib crate and separate binaries for the main scale code and the
    manual calibration code.
    Eventually, we'll likely want separate binaries for each board variant
    and and to think harder about how to move common code into the lib
    crate. Ideally, the code in the binaries will be entirely
    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
2023-08-21 Return dummy responses to speed up connection
    The Tindeq app queries a few parameters on connection and also when the
    settings page is opened in the app:
    * Versino number
    * Battery voltage
    * Progressor ID (undocumented query with opcode 0x70)
    These requests were being ignored. Although the app eventually gives up
    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
2023-08-21 Add advertising timeout and sleep between connections
    * Add 3 minute advertising timeout
    * Require user to press power button to start advertising in all cases
    (startup, after a timeout, or after a disconnect). The CPU will enter
    WFI sleep (System On) while waiting. This saves power by not doing BLE
    things all the time.
    * Add a separate binary for the OG development dongle. This allows the
    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
2023-08-25 Enter system OFF between BLE connections to save power
    * Enter system OFF after advertising timeouts or disconnects, using the
    wakeup button as the wakeup trigger.
    * Minor cleanup: centralize the definition of the `blocking_hal` and pac
    crates to make it easier to switch to other nRF52 parts in the future.
2023-08-26 Reduce SoftDevice RAM usage via easy-mode tuning
    * Reduce SoftDevice RAM memory usage from ~15kB to ~8kB, knowing that we
    only support one connection at a time and should only need a small
    MTU. This gives even more headroom to use smaller nRF52 devices, if
    desired, which only have 24kB of RAM.
    * Allow 2M secondary Phy. This might save some marginal power by running
    the radio less.
2023-08-26 Inject sampling frequency from binary
    The dongle development setup is configured with a 10Hz sampling
    frequency, whereas everything else uses 80Hz. Allow this parameter to be
    injected into the weight task rather than hard-coding it.
    The sampling frequency is primarily used for configuring the taring
    process. Accidentally using the default 80Hz value with the dongle
    results in very slow startup.
2023-08-26 Enable DC-DC converter for power savings
    The MCU should automatically switch between the DC-DC converter and the
    LDO to optimize conversion efficiency. Didn't actually measure power
    with and without this change but it _should_ work 😬
    [dongle.rs, proto0_0.rs]
2023-08-29 Add proto1_0 board
    Add schematic and PCB for another prototype board, P1.0.
    Main changes from the first prototype PCB (P0.0):
    * Based on TI ADS1230 ADC IC rather than HX711
    * More thoughtful layout of ADC
    * Using Fanstel BT832 module rather than a Nordic USB dongle
    This will require some software changes to get working in a future
    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
    [proto1_0-B_Cu.gbl, proto1_0-B_Mask.gbs, proto1_0-B_Paste.gbp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]
2023-09-10 Fix bad transistor pin assignment
    The load cell power switch (Q1) used a PFET symbol that incorrectly
    numbered its pins relative to the industry-standard for SOT-23 packages.
    Use a more accurate symbol instead and fix the layout accordingly.
    While a P1.1 board is not (yet) planned since this issue should be easy
    to work around,, I've kept the footprint locations the same so that the
    P1.0 stencil can be reused.
    [proto1_0.kicad_pcb, proto1_0.kicad_sch]
2023-09-25 Allow registration of a system OFF callback
    Allow registration of a callback that will be called right before
    transitioning to the system OFF state. This allows binary-specific
    behavior e.g. turning off an analog supply to save power .
2023-09-25 Add support for Proto 1.0 board
    * Add mutually-exclusive feature flags for nRF52832 and nRF52840. This
    abuses the feature flag system, but that's embedded life for you.
    Embassy also uses this pattern.
    * Add ADS1230 driver
    * Add blinky, calibration, and application binaries for Proto 1.0
    Note: Some library code abuses the nRF52832 vs. nRF52840 feature flags
    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
2023-09-25 Fix flipped PCB silkscreen
    The white and green color labels for the load cell differential output
    voltage pins were switched. There's no real functional effect since the
    negative polarity would be fixed in calibration, but one can swap the
    wires if desired.
    [proto1_0.kicad_pcb, proto1_0.kicad_sch]
2023-09-25 Add missing license headers
    [blinky_p0.rs, blinky_p1.rs, calibration_p0.rs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]
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2023-10-01 Random cleanup 🧹
    * Remove obsolete leds module
    * Use `RawReading` type in more places
    * Fix a Clippy lint
    [dongle.rs, sleep.rs, task.rs]
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2023-10-04 Fix advertised device name
    The advertising data was missing the
    `BLE_GAP_AD_TYPE_COMPLETE_LOCAL_NAME` flag, leading it to show up as a
    blank device name in the Tindeq app.
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2023-10-07 Remove nagging error message at connection time
    * Provide response to get calibration curve control message. The default
    value can be overridden at compile time via the `CALIBRATION_CURVE`
    environment variable.
    * Add support for device ids up to 8 bytes
2023-10-09 Fix typos caught by Mark and Chris
    [proto1_0.rs]
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2023-10-13 Update dependencies and fix new warnings
    Notable changes
    * Updating Embassy was, as usual, a minor pain.
    * Embassy requires a more recent of the nightly compiler.
    * There was a breaking API change to a embassy_sync channel API, but
    luckily it was just a name change.
    * The compiler advised against using async functions in public traits.
    Rather than following the recommended syntax workaround, I took the hint
    and reduced the visibility of the SampleProducer traits, which don't
    need to be public.
    * Remove the fix-hidden-lifetime-bug crate, which is no longer needed as
    of Rust 1.69.
    [task.rs]
2024-01-23 Pull Embassy crates from crates.io 🎉
    Embassy published their crates to crates.io so we no longer need to add
    them as git dependencies. This should remove the previously-encountered
    pain of breaking API changes suddenly breaking things.
    Also remove the `async_fn_in_trait` nightly feature flag now that it's
    on stable.
    [blinky_p0.rs, blinky_p1.rs, calibration_p0.rs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]
2024-07-06 Re-implement broken make_static! macro
    static-cell's `make_static!` macro is broken in latest nightly:
    https://github.com/embassy-rs/static-cell/issues/16
    Re-implement it by dropping the automatic type deduction magic.
    [blinky_p0.rs, blinky_p1.rs, calibration_p0.rs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]
2025-09-03 Remove gerbers from git history
    Remove gerbers from git history so that the Kicad files remain as the
    source of truth.
    [proto1_0-B_Cu.gbl, proto1_0-B_Mask.gbs, proto1_0-B_Paste.gbp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]
